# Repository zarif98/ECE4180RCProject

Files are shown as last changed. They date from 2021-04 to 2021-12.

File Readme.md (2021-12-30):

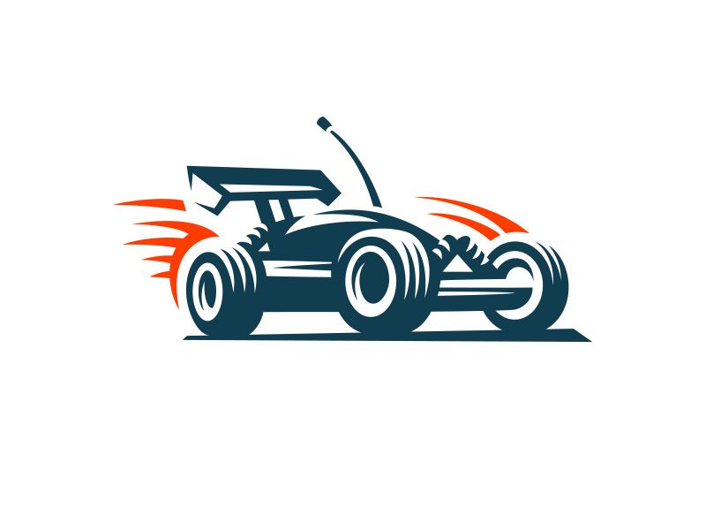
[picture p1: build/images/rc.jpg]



&nbsp;&nbsp;&nbsp;&nbsp;&nbsp;&nbsp;&nbsp;&nbsp;&nbsp;&nbsp;&nbsp;&nbsp;&nbsp;&nbsp;&nbsp;&nbsp;&nbsp;&nbsp;&nbsp;
<!--![Python](https://img.shields.io/badge/python-v3.6+-blue.svg)
[![Build Status](https://travis-ci.org/anfederico/Clairvoyant.svg?branch=master)](https://travis-ci.org/anfederico/Clairvoyant)
![Dependencies](https://img.shields.io/badge/dependencies-up%20to%20date-brightgreen.svg)
[![GitHub Issues](https://img.shields.io/github/issues/anfederico/Clairvoyant.svg)](https://github.com/zarif98/ECE4180RCProject/issues)
![Contributions welcome](https://img.shields.io/badge/contributions-welcome-orange.svg)
[![License](https://img.shields.io/badge/license-MIT-blue.svg)](https://opensource.org/licenses/MIT)-->

Checkout the website: http://zarifandr.com/ECE4180RCProject/

## Basic Overview
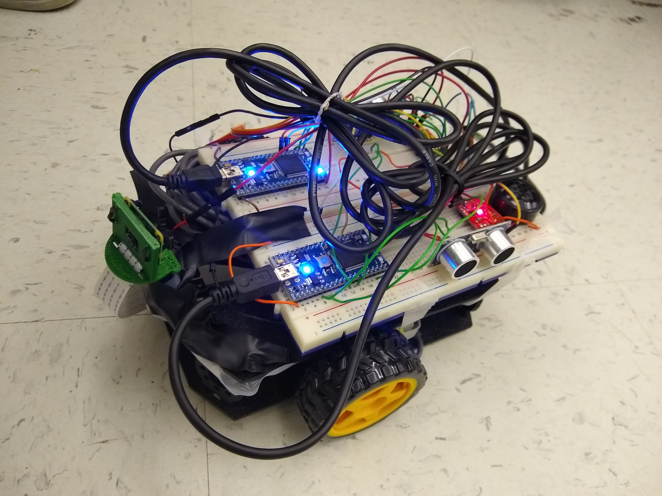
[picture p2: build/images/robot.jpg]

We built an RC car using the shadow chassis that was controlled with Xbox controls that were processed by the Raspberry Pi 4. There was also a Pi camera mounted on the front of the car on a servo motor that will turn. The Pi video stream is accessible on a web app accessible by anyone on the same wifi network. Two sonar systems were mounted on the left and right sides. If the sonars sensed anything on the sides of the car, it would cause the speakers to "honk". An Anker portable battery was used to power the Pi which in turn powered the entire system.

<br>

## Latest Development Changes

```bash
git clone https://github.com/zarif98/ECE4180RCProject.git
```

# Setup

## Assembling the Shadow Chasis Robot

Click on the image below to watch the video guide
SparkFun - Shadow Chassis Assembly Guide (http://www.youtube.com/watch?v=aJRYTqZu5OE&t "SparkFun - Shadow Chassis Assembly Guide")

## Connecting the Controller

Follow these steps to connect the Xbox One controller to the Raspberry Pi:

```
https://pimylifeup.com/xbox-controllers-raspberry-pi/
```

The source code to run the controller can be found in the Pi-Controller folder. The Pi-contoller code looks for 6 different inputs: X and Y of the left analog joystick (for driving), Left and Right Triggers (for moving the camera), and A and B button (for playing sounds). This code runs simultaneously with the Pi camera stream code.

## Streaming and Pi Camera

The RC car is equipped with a Pi cam at the front of the car. The camera is powered by a Raspberry Pi 4. The streaming website is written in Flask and interfaces with the camera. I would recommend running the website on a phone hotspot rather than GT wifi. Your website address should look something similar to this:

```
<raspberry_pi_ip:5000>
```

The Pi cam was also equipped with motion detection due to the fact that object detection runs at a measly 2fps on the Pi 4. We can maintain our 24fps on the Raspi 4 with motion detection running at 5fps. Fork over the Pi Stream folder to run the code and hit main.py

<br>
Here's our Camera.py code. For more information click on the Pi-camera -stream-flask folder

```
import cv2
from imutils.video.pivideostream import PiVideoStream
import imutils
import time
import numpy as

class VideoCamera(object):
    def __init__(self, flip = False):
        self.vs = PiVideoStream().start()
        self.flip = flip
        time.sleep(2.0)

    def __del__(self):
        self.vs.stop()

    def flip_if_needed(self, frame):
        if self.flip:
            return np.flip(frame, 0)
        return frame

    def get_frame(self):
        frame = self.flip_if_needed(self.vs.read())
        ret, jpeg = cv2.imencode('.jpg', frame)
        return jpeg.tobytes()
```

# Mbed Code

## Mbed 1: Servo and DC Motors
This is the code for the first mbed we used. This mbed was used to process the Pi serial commands from the Xbox controller that controlled the H-bridge for the two motors as well as the servo motor.

```
#include "mbed.h" // using namespace mbed; from Lab3-4_BT
#include "Motor.h" // #include "motordriver.h" // equivalent to DCMotor.h from class... might be more useful
//#include "uLCD_4DGL.h" // debugging
#include <cstdlib>
#include <string>
#include <string.h>
#include <ctype.h>
#include "Speaker.h"
#include "Servo.h"

Motor motor_right(p25, p20, p23); // pwm a, fwd (AI1), rev (AI2)
Motor motor_left(p26, p21, p22); // pwm b, fwd (BI1), rev (BI2)
Serial pi(USBTX, USBRX); // RawSerial
Servo cam_servo(p24); //Servo
DigitalOut mbed_led1(LED1);
DigitalOut mbed_led2(LED2);

const int MAX_BUFFER_SIZE = 128; // max number of possible chars -> pow2
char buffer[MAX_BUFFER_SIZE];
float buffer_to_int[6];
int spaces[6];

bool left = true;

int main() {
    mbed_led1 = 1;
    pi.baud(9600);
    while(1) {
        mbed_led1 = !mbed_led1;
        wait(0.2);
        int index = 0;
        buffer[0] = '\0';
        while (pi.readable() && index < MAX_BUFFER_SIZE) {
            buffer[index++] = pi.getc();
        }
        spaces[0] = -1;
        int i = 0;
        int count = 1;
        while (buffer[i]) {
            if (isspace(buffer[i])) {
                spaces[count++] = i;
            }
            i++;
        }
        for (int i = 0; i < 5; i++) {
            int starting = spaces[i] + 1;
            int ending = spaces[i+1];
            string s = "";
            while (starting < ending) {
                mbed_led2 = !mbed_led2;
                s += buffer[starting++];
            }
            buffer_to_int[i] = atof(s.c_str());
        }

        motor_left.speed(buffer_to_int[0]);
        motor_right.speed(-buffer_to_int[1]);

        float turn_left_cam = buffer_to_int[2];
        float turn_right_cam = buffer_to_int[3];
        if (turn_left_cam < 0 || turn_right_cam < 0 || // not triggering
                turn_left_cam > 0 && turn_right_cam > 0 || // holding both triggers
                cam_servo == 0.0 && turn_left_cam > 0 || // max left
                cam_servo == 1.0 && turn_right_cam > 0) { // max right
            float increm = (turn_left_cam > 0 ? -1 * cam_servo * 0.1 : -(1-cam_servo) * 0.1);
            float new_pos = cam_servo + increm;
            cam_servo = (new_pos > 1.0 ? 1.0 : (new_pos < 0.0 ? 0.0 : new_pos));
        }
    }
}
```
## Mbed 2: Sonar and Sound
This is the code for the second mbed we used. This mbed controlled the two sonars to trigger a "honk" if an object gets within a half of an inch of the RC car.
```
#include "mbed.h" // using namespace mbed; from Lab3-4_BT
#include "Motor.h" // #include "motordriver.h" // equivalent to DCMotor.h from class... might be more useful
#include "ultrasonic.h"
#include <stdlib.h>
#include <string.h>
#include "Speaker.h"

Speaker speaker(p18);

void dist(int distance) // left
{
    //put code here to execute when the distance has changed
    float x = float(distance)*(0.00328084);
    if (x  < .5) {
        speaker.PlayNote(500, 0.5, 0.5);
    }
}

void dist1(int distance) // right
{
    //put code here to execute when the distance has changed
    float x = float(distance)*(0.00328084);
    if (x  < .5) {
        speaker.PlayNote(500, 0.5, 0.5);
    }    
}

ultrasonic mu_left(p6, p7, .1, 1, &dist);
ultrasonic mu_right(p12, p13, .1, 1, &dist1);

int main() {
    
    mu_left.startUpdates();
    mu_right.startUpdates();
    
    while(1) {
        mu_right.checkDistance();
        mu_left.checkDistance();
    }   
}
```
# Hardware

## Parts List

<br>

| Part Name | Quantity |
| :---: | :---: |
| mbed LPC1768 | 2 |
|  Hobby DC Gear Motor - 140 rpm | 2 |
| Shadow Robot Chassis | 1 |
| Sparkfun Dual H Bridge | 1 |
| Battery Holder | 1 |
| Xbox One Controller | 1 |
| Raspberry Pi 4 | 1 |
| Raspberry Pi Cam V2.1 | 1 |
| HC-SR04 (Sonar Sensor) | 2 |
| Speaker PCB Mount | 1 |
| SparkFun Mono Audio Amp Breakout | 1 |
| Anker Portable Battery | 1 |
| Micro Servo SG90 | 1 |

<br>
<br>

## Wheel Motors and H-Bridge Pinouts

| Mbed 1 | Dual H-Bridge | Left DC Motors | Right DC Motors | Pin 2 on Pi | Pin 6 on Pi |
| :----: | :---: | :---: | :---: | :---: | :---: |
|  Vout  | Vcc, STBY | nc | nc | nc | nc |
| nc | Vm | nc | nc | 5V+ | nc |
|  GND | GND | nc | nc | nc | GND |
|  P26 | PWMB | nc | nc | nc | nc |
|  P25 | PWMA | nc | nc | nc | nc |
|  P20 | AI1 | nc | nc | nc | nc |
|  P23 | AI2 | nc | nc | nc | nc |
|  P22 | BI2 | nc | nc | nc | nc |
|  P21 | BI1 | nc | nc | nc | nc |
| nc | A01 | + | nc | nc | nc |
| nc | A02 | - | nc | nc | nc |
| nc | B01 | nc | + | nc | nc |
| nc | B02 | nc | - | nc | nc |

## Speaker and Mono Audio Amp Pinouts

| Mbed 2 | Mono Audio Amp | Speaker | Pin 2 on Pi | Pin 6 on Pi |
| :----: | :---: | :-----: | :---: | :---: |
|  P18 | IN+ | nc | nc | nc |
|  GND | PWR-, IN- | nc | nc | GND |
| nc | OUT+ | + | nc | nc |
| nc | OUT- | - | nc | nc |
| nc | PWR+ | nc | 5V+ | nc |

## Left Side Sonar Sensor Pinouts

| Mbed 2 | Left HC-SR04 | Pin 2 on Pi | Pin 6 on Pi |
| :----: | :---: | :---: | :---: |
|  GND | GND | nc | GND |
| nc | Vcc | 5V+ | nc |
| P6 | Trig | nc | nc |
| P7 | Echo | nc | nc |

## Right Side Sonar Sensor Pinouts

| Mbed 2 | Right HC-SR04 | Pin 2 on Pi | Pin 6 on Pi |
| :----: | :---: | :---: | :---: |
|  GND | GND | nc | GND |
| nc | Vcc | 5V+ | nc |
|  P12 | Trig | nc | nc |
|  P13 | Echo | nc | nc |

## Pi Camera Servo Motor

| Mbed 1 | Micro Servo SG90 | Pin 2 on Pi | Pin 6 on Pi |
| :----: | :---: | :---: | :---: |
|  GND | Brown | nc | GND |
| nc | Red | 5V+ | nc |
|  P24 | Orange | nc | nc |

## Pi Camera Servo Mount

The pi camera servo mount was designed based off an existing servo mount but it was extend to include a semi-circle base that contained the pi camera mount on it. The mount was 3D printed at the Invention Studio in the MDCR. It was mounted to the microservo motor using a screw. The STereoLithography (STL) file and inventor file are included on the GitHub page.

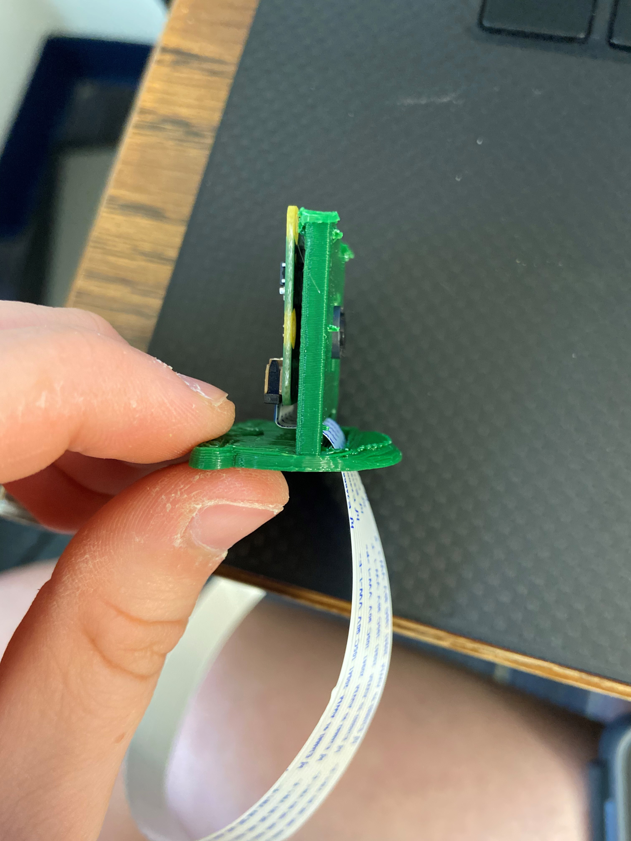
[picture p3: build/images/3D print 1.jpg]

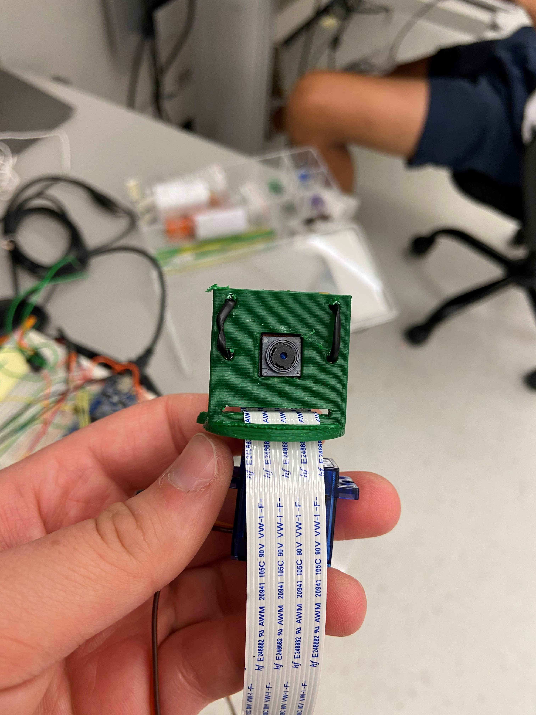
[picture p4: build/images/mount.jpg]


# Demo

RC Car Demo (https://www.youtube.com/watch?v=TS9khvXI--E "RC Car Demo")

# Presentation

RC Car Presentation (https://www.youtube.com/watch?v=KlX4RG750h4 "RC Car Presentation")

# Contributing

Feel free to fork over and utilize our code for future projects. Our goal was to utilize the material that we accumulated over the semester in our embedded systems class and combine the skills we learned into one project.

#### Team Members

- Nicole Komocsar
- Zarif Rahman
- Marcus Chan
- Alan Jin

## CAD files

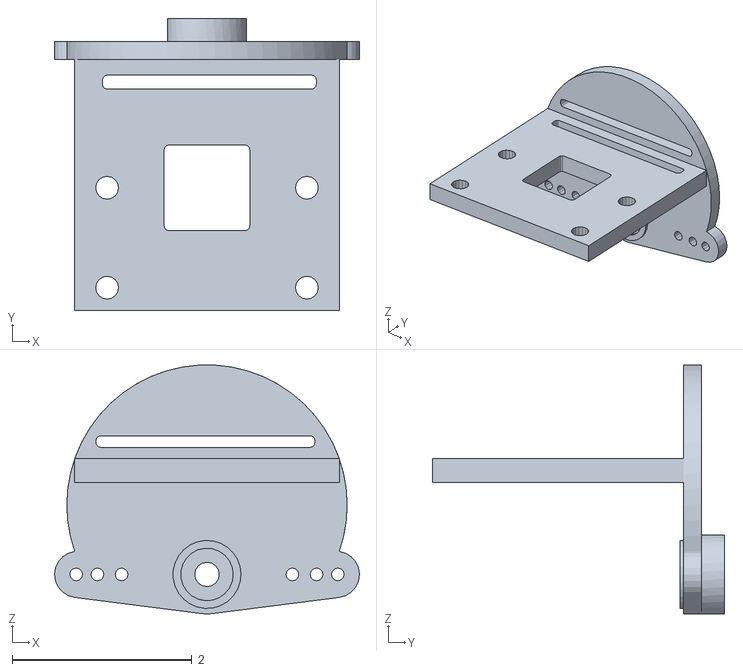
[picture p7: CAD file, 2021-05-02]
Swiveling Camera mount/horn straight plus pi camera mount update.stl
3.39 x 3.25 x 2.77

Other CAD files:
Swiveling Camera mount/horn straight plus pi camera mount update.ipt

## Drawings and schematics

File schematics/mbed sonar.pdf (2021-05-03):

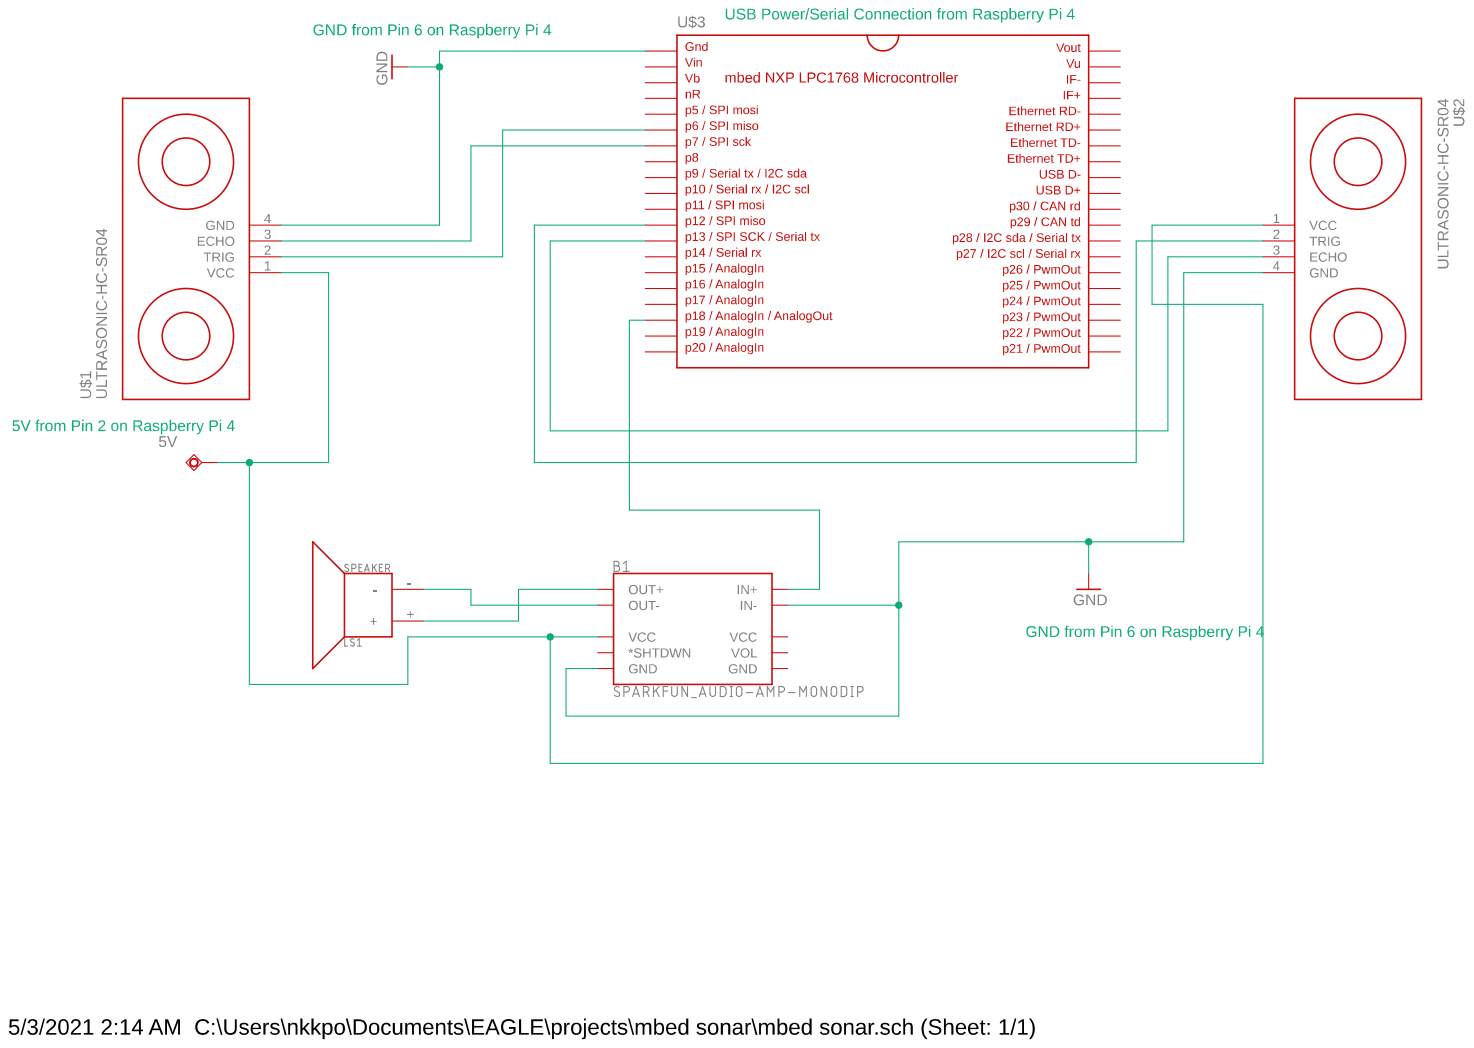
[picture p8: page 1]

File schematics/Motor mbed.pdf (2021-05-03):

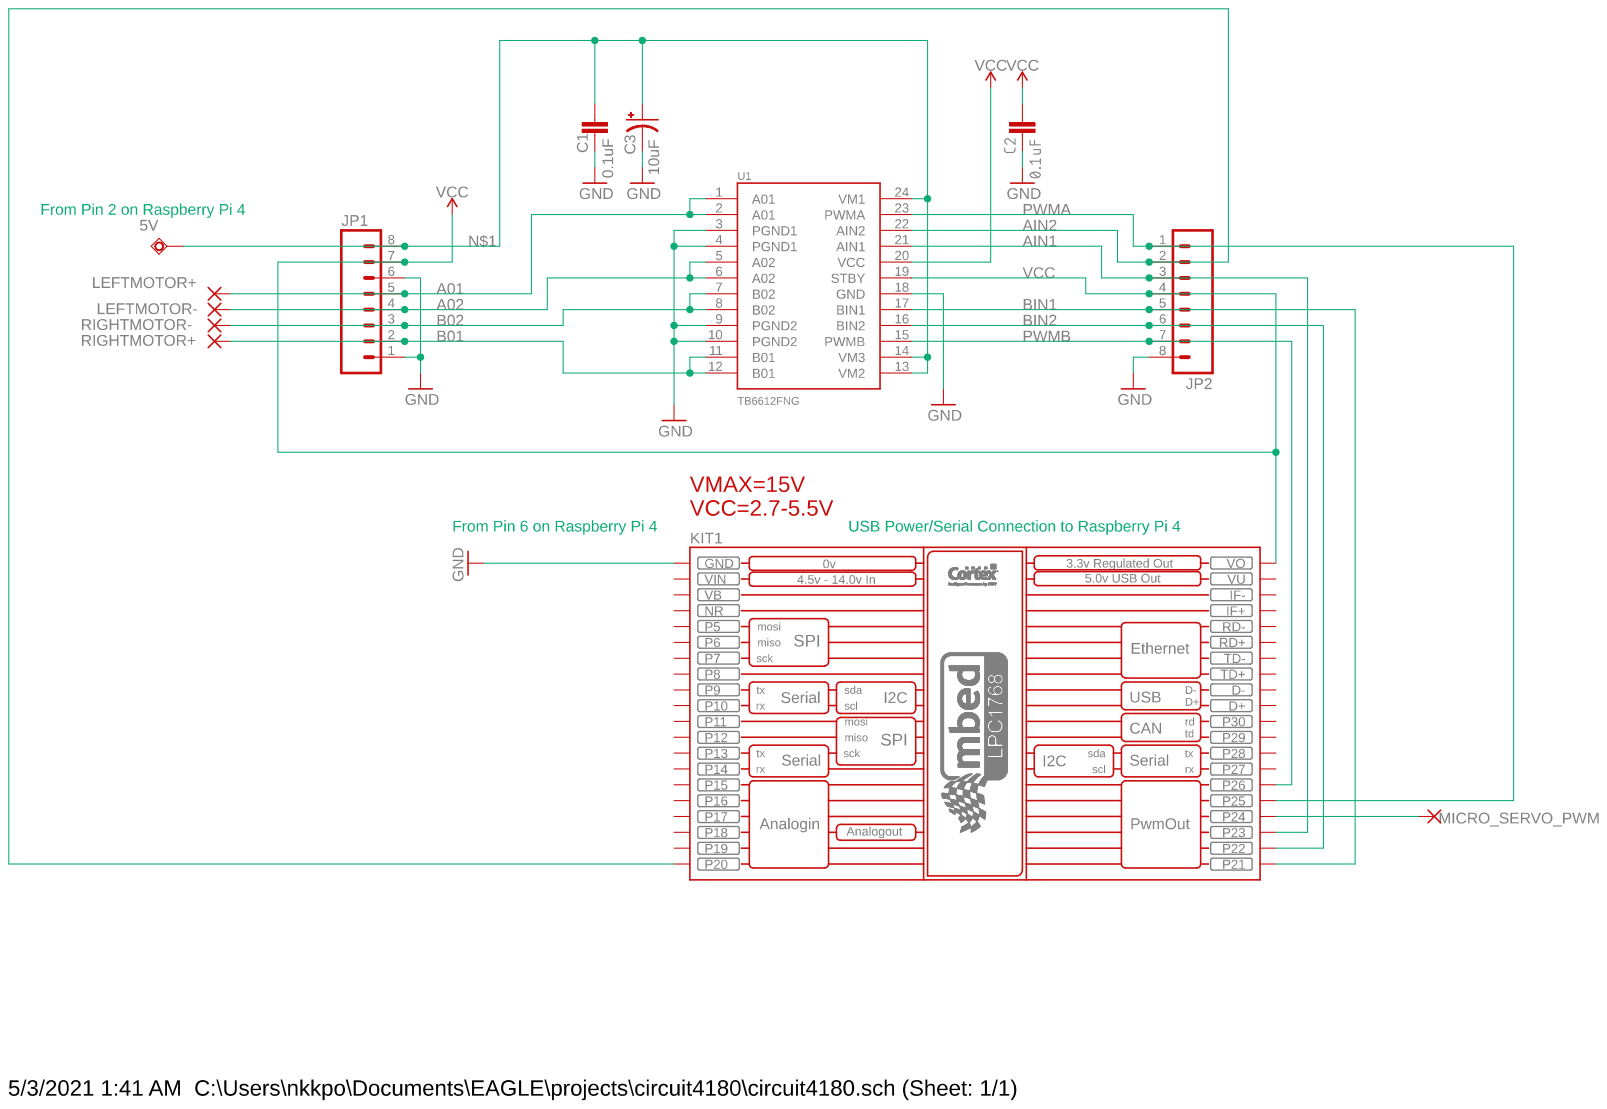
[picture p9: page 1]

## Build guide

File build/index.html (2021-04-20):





    (https://github.com/zarif98/ECE4180RCProject/issues)   (https://opensource.org/licenses/MIT)

# To Do (Delete after)#

- Team members
- parts list
- schematic
- source code
- photos & videoes
- Powerpoint for video presentation (6 slides max) final slide for further ideas

## Basic Overview#

Build an RC car using the shadow chassis with Xbox controls and Pi cam at the front. The Pi streams video onto a web app accessible by anyone on the same wifi network.

## Visualize the Learning Process#



## Last Stable Release#

pip install clairvoyant

## Latest Development Changes#

git clone https://github.com/anfederico/Clairvoyant

## Backtesting Signal Accuracy#

During the testing period, the model signals to buy or sell based on its prediction for price movement the following day. By putting your trading algorithm aside and testing for signal accuracy alone, you can rapidly build and test more reliable models.

from clairvoyant.engine import Backtest
import pandas as pd

features  = ["EMA", "SSO"]   # Financial indicators of choice
trainStart = 0               # Start of training period
trainEnd   = 700             # End of training period
testStart  = 701             # Start of testing period
testEnd    = 1000            # End of testing period
buyThreshold  = 0.65         # Confidence threshold for predicting buy (default = 0.65)
sellThreshold = 0.65         # Confidence threshold for predicting sell (default = 0.65)
continuedTraining = False    # Continue training during testing period? (default = false)

# Initialize backtester
backtest = Backtest(features, trainStart, trainEnd, testStart, testEnd, buyThreshold, sellThreshold, continuedTraining)

# A little bit of pre-processing
data = pd.read_csv("SBUX.csv", date_parser=['date'])
data = data.round(3)

# Start backtesting and optionally modify SVC parameters
# Available paramaters can be found at: http://scikit-learn.org/stable/modules/generated/sklearn.svm.SVC.html
backtest.start(data, kernel='rbf', C=1, gamma=10)
backtest.conditions()
backtest.statistics()
backtest.visualize('SBUX')

#### Output#

------------ Data Features ------------

X1: EMA
X2: SSO

---------------------------------------

----------- Model Arguments -----------

kernel: rbf
C: 1
gamma: 10

---------------------------------------

---------  Engine Conditions ----------

Training: 2013-03-01 -- 2015-12-09
Testing:  2015-12-10 -- 2017-02-17
Buy Threshold: 65.0%
Sell Threshold: 65.0%
Continued Training: False

---------------------------------------

------------- Statistics --------------

Total Buys: 170
Buy Accuracy: 68.24%
Total Sells: 54
Sell Accuracy: 59.3%

---------------------------------------



## Simulate a Trading Strategy#

Once you've established your model can accurately predict price movement a day in advance, simulate a portfolio and test your performance with a particular stock. User defined trading logic lets you control the flow of your capital based on the model's confidence in its prediction and the following next day outcome.

def logic(account, today, prediction, confidence):

    if prediction == 1:
        Risk         = 0.30
        EntryPrice   = today['close']
        EntryCapital = account.BuyingPower*Risk
        if EntryCapital >= 0:
            account.EnterPosition('Long', EntryCapital, EntryPrice)

    if prediction == -1:
        ExitPrice = today['close']
        for Position in account.Positions:
            if Position.Type == 'Long':
                account.ClosePosition(Position, 1.0, ExitPrice)

simulation = backtester.Simulation(features, trainStart, trainEnd, testStart, testEnd, buyThreshold, sellThreshold, continuedTraining)
simulation.start(data, 1000, logic, kernel='rbf', C=1, gamma=10)
simulation.statistics()
simulation.chart('SBUX')

#### Output#

------------- Statistics --------------

Buy and Hold : -6.18%
Net Profit   : -61.84
Strategy     : 5.82%
Net Profit   : 58.21
Longs        : 182
Sells        : 168
Shorts       : 0
Covers       : 0
--------------------
Total Trades : 350

---------------------------------------



### Hardware#

## Required Parts#

The primary purpose of this project is to rapidly test datasets on machine learning algorithms (specifically Support Vector Machines). While the Simulation class allows for basic strategy testing, there are other projects more suited for that task. Once you've tested patterns within your data and simulated a basic strategy, I'd recommend taking your model to the next level with:

Part Name | Quantity
mbed LPC1768 | 1
Hobby DC Gear Motor - 140 rpm | 2
Shadow Robot Chassis | 1
Smartfun Dual H Bridge | 1
HC05 Bluetooth Module | 1
Battery Holder | 1
Xbox One Controller | 1
Raspberry Pi 4 | 1
Raspberry Pi Cam V2.1 | 1
HC-SR04(Sonar Sensor) | 2

# Pinouts#

Mbed | Dual H-Bridge | DC Motors | Battery
Vin | Vmot

#### Social Sentiment Scores#

The examples shown use data derived from a project where we are data mining social media and performing stock sentiment analysis. To get an idea of how we do that, please take a look at:

https://github.com/anfederico/Stocktalk

## Notes#

#### Multivariate Functionality#

Remember, more is not always better!

variables = ["SSO"]                            # 1 feature
variables = ["SSO", "SSC"]                     # 2 features
variables = ["SSO", "SSC", "RSI"]              # 3 features
variables = ["SSO", "SSC", "RSI", ... , "Xn"]  # n features

## Contributing#

Please take a look at our contributing (https://github.com/anfederico/Clairvoyant/blob/master/CONTRIBUTING.md) guidelines if you're interested in helping!

#### Team Members#

- Nicole Komocsar
- Zarif Rahman
- Marcus Chan
- Alan Jin
- To Do (Delete after)
- Pinouts
- To Do (Delete after)
  - Basic Overview
  - Visualize the Learning Process
  - Last Stable Release
  - Latest Development Changes
  - Backtesting Signal Accuracy
      - Output
  - Simulate a Trading Strategy
      - Output
    - Hardware
  - Required Parts
- Pinouts
      - Social Sentiment Scores
  - Notes
      - Multivariate Functionality
  - Contributing
      - Team Members

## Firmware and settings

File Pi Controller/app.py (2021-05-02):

#!/usr/bin/env python
# coding: Latin-1
# The code

# Load library functions we want
import time
import pygame
import serial

# Axis config for controller
rightThumbUpDown = 3                    #Joystick Axis Right Thumb
leftThumbUpDown = 1                     #Joystick Axis Left Thumb
leftTrig = 5                            #Joystick Axis Left Trigger
rightTrig = 4                           #Joystick Axis Right Trigger
aButton = 0                             #Joystick A Button
bButton = 1                             #Joystick B Button
interval = .1                          #Time between keyboard updates in seconds, smaller responds faster but uses more processor time

# Setup pygame and key states
global hadEvent
global moveQuit
global rightUpDownVal 
global leftUpDownVal
global lTrigVal
global rTrigVal
global aVal
global bVal
rightUpDownVal = 0
leftUpDownVal = 0
lTrigVal = -1
rTrigVal = -1
aVal = 0
bVal = 0
hadEvent = True
moveQuit = False
pygame.init()
pygame.joystick.init()
joystick = pygame.joystick.Joystick(0)
joystick.init()
screen = pygame.display.set_mode([300,300])
pygame.display.set_caption("JoyBorg - Press [ESC] to quit")

# Function to handle pygame events
def PygameHandler(events):
    # Variables accessible outside this function
    global hadEvent
    global moveQuit
    global rightUpDownVal 
    global leftUpDownVal
    global lTrigVal
    global rTrigVal
    global aVal
    global bVal
    # Handle each event individually
    for event in events:
        if event.type == pygame.QUIT:
            # User exit
            hadEvent = True
            moveQuit = True
        elif event.type == pygame.KEYDOWN:
            # A key has been pressed, see if it is one we want
            hadEvent = True
            if event.key == pygame.K_ESCAPE:
                moveQuit = True
        elif event.type == pygame.KEYUP:
            # A key has been released, see if it is one we want
            hadEvent = True
            if event.key == pygame.K_ESCAPE:
                moveQuit = False
        elif event.type == pygame.JOYAXISMOTION:
            # A joystick has been moved, read axis positions (-1 to +1)
            hadEvent = True
            rightUpDownVal = joystick.get_axis(rightThumbUpDown)
            leftUpDownVal = joystick.get_axis(leftThumbUpDown)
            lTrigVal = joystick.get_axis(leftTrig)
            rTrigVal = joystick.get_axis(rightTrig)
        elif event.type == pygame.JOYBUTTONDOWN:
            hadEvent = True
            aVal = joystick.get_button(aButton)
            bVal = joystick.get_button(bButton)
            
# Loop indefinitely
# Make Serial connection

print('Press [ESC] to quit')

while True:
    # Get the currently pressed keys on the keyboard
    PygameHandler(pygame.event.get())
    if hadEvent:
        # Keys have changed, generate the command list based on keys
        hadEvent = False
        if moveQuit:
            break
        # Write to Serial Port values:
        # left thumb x-axis, left thumb y-axis, left trigger, right trigger, a button, b button
        values = [-leftUpDownVal, -rightUpDownVal, lTrigVal, rTrigVal, aVal, bVal]
        roundedvalues = [0,0,0,0,0,0]
        for i in range(len(values)):
            roundedvalues[i] = round(values[i],2)
        string = ' '.join(str(i) for i in roundedvalues)
        new_string = string.encode()
        print(new_string)
        device = serial.Serial('/dev/ttyACM0')
        device.write(new_string)
        device.close()
    # Wait for the interval period
    time.sleep(interval)

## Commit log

2021-04-28 Added Camera Streaming description
2021-05-02 Added CAD files for the swivelling camera
    [horn straight plus pi camera mount update.ipt, horn straight plus pi camera mount update.stl]
2021-05-06 Added Pi Camera.py code
